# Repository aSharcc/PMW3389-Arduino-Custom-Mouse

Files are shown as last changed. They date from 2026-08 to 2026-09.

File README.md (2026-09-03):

Video Example of Mouse

# PMW3389 Custom DIY Mouse

A fully custom gaming mouse using a PixArt PMW3389.

2 versions. 3.3V/8MHz Arduino Pro Micro (ATmega32U4) and Seeed Studio XIAO ESP32C3.

I also intend for this mouse to be easily repairable.

Be sure to read [BOM.md](docs/BOM.md)

## Key Features

- High performance sensor: 16,000 DPI via PixArt PMW3389
- Modular and Repairable
	- Hotswap Main Switches: Uses Mill-Max 3305 so can be replaced with no soldering
	- Replaceable MCU: Mounted using through-hole pin headers
- Wireless and wired versions.
- Sensor communication through SPI

## Version Comparison

|Features|v2 (Wired)|v3 (Wireless)|
|---|---|---|
|MCU|3.3V/8MHz Arduino Pro Micro (ATmega32U4)|Seeed Studio XIAO ESP32C3|
|Connectivity|Micro-USB|Bluetooth / 2.4GHz Wireless|
|Power Source|Micro-USB|LiPo Battery|
|Production Files|[Files v2](https://github.com/aSharcc/PMW3389-Custom-Mouse/releases/tag/2.0)|[Files v3](https://github.com/aSharcc/PMW3389-Custom-Mouse/releases/tag/3.0)|

## How To Use

**DETAILED INSTRUCTIONS and BOM [HERE](docs/BOM.md)**

1. Order the PCB from a PCB manufacturer (e.g. JLCPCB) with files from specific release.
2. Either:
   - Order PCBA for the SMD components, or
   - Purchase the SMD components and hand solder them.
3. Purchase the components listed in the BOM that are not included in PCBA.
4. Hand solder/install the components not included in PCBA.
5. Download the PMW3389 library.
	- For Wired: [Arduino Library](Firmware/Arduino/README.md) for instructions.
	- For Wireless: **NOT COMPLETED**
6. Download Firmware
	- For Wired: [Arduino Firmware](https://github.com/aSharcc/PMW3389-Custom-Mouse/releases/download/2.0/Mouse.Firmware.ino)
	- For Wireless: **NOT COMPLETED**
7. Flash the firmware to the MCU.
8. Download and print the 3D models.
	- For Wired: [Top](https://github.com/aSharcc/PMW3389-Custom-Mouse/releases/download/2.0/Mouse.Shell.top.gcode.3mf) + [Bottom](https://github.com/aSharcc/PMW3389-Custom-Mouse/releases/download/2.0/Mouse.Shell.bottom.gcode.3mf) + [Scroll](https://github.com/aSharcc/PMW3389-Custom-Mouse/releases/download/2.0/Mouse.Shell.knob.gcode.3mf)
	- For Wireless: **NOT COMPLETED**
9. Add threaded heat inserts to the shell.
10. **For Wireless Only**:
	- **Not Completed** Will include power switch and battery stuff.
11. Assemble the mouse.

## Components

- Sensor: PixArt PMW3389 and LM19-LCT Lens

- MCU: 3.3V/8MHz Arduino Pro Micro (ATmega32U4) or Seeed Studio XIAO ESP32C3

- Switches: 2 x Huano Blue Shell Pink Dot Mouse Switches 

- Scroll Wheel: Rotary Encoder w/Switch (EC11)

- Hot Swap Socket for Switches: 6 x Mill-Max 3305

- SMD Components (0805)
	- 1 x 13 ohm resistor
	- 1 x 10k ohm resistor
	- 5 x 0.1uF capacitor
	- 3 x 10uF capacitor
	- 1 x 4.7uF capacitor
	- 1 x XC6206-1.8V LDO

- PTFE Mouse Skates

- Micro USB Cable for v2 or USB-C cable for v3 charging

- Mounting Hardware
	- 7 x Heat Inserts M2 x 3 x 3.2
	- 3 x M2 x 4 Screw
	- 4 x M2 x 7 Screw

- **FOR V3 ONLY**:
	- 500mAh battery with JST connector
	- SPDT / 1P2T PCB slide switch

## Pinout

|Component|Usage|v2 (3.3v/8MHz Pro Micro)|v3 (XIAO ESP32)|
|---|---|---|---|
|**PMW3389**|NCS|D10|D3|
||MOSI|D16 (MOSI)|D10 (MOSI)|
||MISO|D14 (MISO)|D9 (MISO)|
||SCLK|D15 (SCLK)|D8 (SCLK)|
||MOT|D2 (INT 1)|D4|
|**Rotary Encoder w/Switch**|Rotary Encoder A|D3 (INT 0)|D6|
||Rotary Encoder B|D7 (INT 6)|D0|
||Encoder Switch S2 (Middle Click)|D8|D7|
|**Switches**|Switch 1 (Left Click)|D4|D1|
||Switch 2 (Right Click)|D9|D2|

## Documentation & Credits

- [Build & Design Log](CHANGELOG.md)
- [Third-Party Credits & Libraries](CREDITS.md)
- [MIT License](LICENSE)

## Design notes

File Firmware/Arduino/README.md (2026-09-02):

# PMW3389 Library

PMW3389 driver library for ATmega32u4 based boards. e.g. Sparkfun Pro Micro

## Features

- Register Read and Write
- SROM firmware upload
- Motion Burst Reads (dx, dy, motion flag, SQUAL)
- DPI/CPI set and get. Range of 100-16000, steps of 50

## Hardware Requirements

- 1.8v-2.1v to VDD with decoupling capacitors (10uF and 100nF)
- 1.8v-3.6v to VDDIO  with decoupling capacitors (10uF and 100nF)
- SPI connection with correct voltage (1.8v-3.6v (same as voltage to VDDIO))
- 13ohm Resistor then 1.8v-2.1v to LED1_P with decoupling capacitors (10uF and 100nF)
- VDDPIX to ground through decoupling capacitors (10uF and 100nF)
- GND wired to Ground

## Installation

**PlatformIO** - Copy this folder into your project's 'lib/' folder

**ArduinoIDE** - Copy this folder into your sketchbook's 'libraries/' directory (usually 'Documents/Arduino/libraries/'), then restart the IDE.

**OR**
- Download [Library Zip File](https://github.com/aSharcc/PMW3389-Custom-Mouse/releases/download/2.0/Library.zip)
- Go to ArduinoIDE
- Sketch->include Library->Add .ZIP Library...->Select downloaded .ZIP file

## API Reference

| Method | Description |
|---|---|
| `PMW3389(uint8_t ncsPin)` | Constructor. Sets which pin is used for chip select. |
| `bool begin()` | Initializes SPI, resets the sensor, uploads SROM firmware. Returns `true` if Product_ID verification passes. |
| `uint8_t readRegister(uint8_t regAddr)` | Reads a single register. |
| `void writeRegister(uint8_t regAddr, uint8_t value)` | Writes a single register. |
| `PMW3389_Motion readMotion()` | Performs a burst read. Returns a struct with `isMotion`, `dx`, `dy`, `squal`. |
| `void setDPI(uint16_t dpi)` | Sets sensor resolution. Clamped to 100–16000, rounded down to the nearest 50. |
| `uint16_t getDPI()` | Reads back the currently set DPI. |

## Usage

``` cpp
#include <PMW3389.h>

PMW3389 sensor(10); // NCS on pin 10

void setup() {
    if (!sensor.begin()) {
        // SROM upload or Product_ID check failed
        while (1);
    }
    sensor.setDPI(1600);
}

void loop() {
    PMW3389_Motion motion = sensor.readMotion();
    if (motion.isMotion) {
        // motion.dx, motion.dy available here
    }
}
```

See `examples/BasicMouse` for a complete mouse implementation with buttons and scroll.

## License

Licensed under MIT license.
[LICENSE](/LICENSE)

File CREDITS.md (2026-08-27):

# Third-Party Credits 

This project was developed using the following third-party resources for
reference, comparison, and component integration.

## Firmware & Technical References

* **PixArt PMW3389 Datasheet:** [PixArt Imaging](https://www.pixart.com/products-detail/4/PMW3389DM-T3QU/)

* **PMW3360/PMW3389 Breakout Board:** [kbjunky/PMW3360](https://github.com/kbjunky/PMW3360/) — MIT License.
  Used to compare and verify hardware designs.

* **PMW3389 Arduino Firmware References:**
  * [Creasento/PWM3389_Arduino](https://github.com/Creasento/PWM3389_Arduino/) — GNU GPL v3.0.
  * [mrjohnk/PMW3389DM](https://github.com/mrjohnk/PMW3389DM/) — used as a reference for understanding PMW3389 communication.

  These projects were used for reference and comparison during development.
  The firmware in this project was written independently.

## KiCad Symbols and Footprints

* **PMW3389 Footprint:** [SnapEDA / PixArt PMW3360DM-T2QU](https://www.snapeda.com/parts/PMW3360DM-T2QU/PixArt/view-part/) — SnapEDA licensing terms / applicable Design Exception.

* **Arduino Pro Micro Footprint:** [SnapEDA / SparkFun DEV-12587](https://www.snapeda.com/parts/DEV-12587/SparkFun%20Electronics/view-part/)

* **Mouse Switch Footprint:** [SnapEDA / Omron D2FC-F-7N(100M)](https://www.snapeda.com/parts/D2FC-F-7N(100M)/Omron/view-part/)

* **Other Components:** KiCad built-in libraries — [KiCad](https://www.kicad.org/).

## 3D CAD References

The following third-party 3D models were used during mechanical development
for component placement, clearance checking, and shell design.

These models are not part of the original design work of this project.

* **PMW3360 Sensor:** [GrabCAD](https://grabcad.com/library/pmw3360dm-mouse-sensor-1)
* **Arduino Pro Micro USB-C:** [GrabCAD](https://grabcad.com/library/arduino-pro-micro-usb-type-c-1)
* **Kailh Mouse Switch:** [GrabCAD](https://grabcad.com/library/tiny-switch-kailh-mouse-1)
* **EC11 Rotary Encoder:** [GrabCAD](https://grabcad.com/library/ec11-rotary-encoder-dode-switch-15mm-1)
* **2.54mm Female Pin Header:** [GrabCAD](https://grabcad.com/library/2-54mm-female-pin-header-1)
* **2.54mm Male Pin Header:** [GrabCAD](https://grabcad.com/library/2-54mm-male-pin-header-1)

The PMW3360 model is used as a mechanical reference for the PMW3389 because
the relevant physical package/footprint is shared.

The female and male pin header models are provided under the
**Free Digital Asset Commercial License v1.9**. Where these models are
redistributed, the original license text is retained with the files.

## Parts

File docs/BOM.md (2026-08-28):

# PMW3389 Custom DIY Mouse - Bill of Materials

## Build information

|Item|Specification|
|---|---|
|Project|PMW3389 Custom DIY Mouse|
|Quantity|1 Mouse|
|PCB|Custom Designed|
|Revision|v2|

## 1. PCB

|Item|Quantity|Required?|Notes|
|---|---|---|---|
|Custom PCB|1|Yes|Manufacture by uploading [this](https://github.com/aSharcc/PMW3389-Arduino-Custom-Mouse/releases/download/2.0/DIY_Mouse.zip) to a PCB manufacturer|

This PCB can be assembled by PCB manufacturer or assembled by hand.

## 2. Surface Mount Components (Placed in PCBA)

|PCB Reference|Qty|Component|Part Number/Value|Package|Notes|
|---|---|---|---|---|---|
|U2|1|LDO Regulator|XC6206-1.8V|SOT-23|XC6206-series 1.8 V LDO; equivalent parts must match the schematic's electrical and pinout requirements.|
|R1|1|Resistor|13 Ω|0805|-|
|R2|1|Resistor|10 kΩ|0805|-|
|C1|1|Capacitor|4.7uF|0805|-|
|C2, C3, C6, C8, C10|5|Capacitor|0.1uF/100nF|0805|-|
|C5, C7, C9|3|Capacitor|10uF|0805|-|
**THERE IS NO C4**

## 3. Through Hole Components (Not in PCBA)

These components are intentionally excluded from PCBA and must be installed by hand.

|Item|Quantity|Notes|
|---|---|---|
|Arduino Pro Micro ATmega32U4 3.3V/8MHz|1|**MUST BE 3.3V/8MHz** Microcontroller for mouse|
|PMW3389|1|Mouse sensor|
|EC11|1|**Should be 15mm and "Plum Handle".**Rotary encoder (Scroll Wheel)|
|Mill-Max 3305 socket|6|Allows for Hot-Swappable switches|
|Huano Blue Shell Pink Dot|2|Mouse switches (Buttons)|
|12-Pin Male Pin Header, 2.54mm Pitch, 1×12|2|Should come with Pro Micro|
|12-Pin Female Pin Header, 2.54mm Pitch, 1×12|2|Allows for replaceable Microcontroller|

## 4. Other Stuff

|Item|Quantity|Notes|
|---|---|---|
|LM-19-LCT Lens|1|Lens for PMW3389, usually sold together|
|PTFE Mouse Skates|5-10|Placed on bottom of mouse to allow for smooth movement|
|USB Cable|1|Get 1m+|

## 5. 3D Printed Parts
|Item|Source|Notes|
|---|---|---|
|Top Shell|[Top Shell 3mf](Mechanical/v2/STLs/Mouse Shell top.3mf)|Keep at rotation, it helps with stepping|
|Bottom shell|[Bottom Shell 3mf](Mechanical/v2/STLs/Mouse Shell bottom.3mf)|-|
|Scroll Knob|[Scroll Knob 3mf](Mechanical/v2/STLs/Mouse Shell knob.3mf)|-|

## 6. Mounting Hardware

|Item|Quantity|Notes|
|---|---|---|
|M2 x 3 x 3.2 Heat Inserts|7|-|
|M2 x 6 Screws|4|-|
|M2 x 4 Screws|3|-|

## 7. Overall Manufacturing

### PCB

- Quantity: 1
- Download [GBR Files](https://github.com/aSharcc/PMW3389-Arduino-Custom-Mouse/releases/download/2.0/DIY_Mouse.zip)
- Download PCBA Files [BOM](https://github.com/aSharcc/PMW3389-Arduino-Custom-Mouse/releases/download/2.0/bom.csv) and [CPL](https://github.com/aSharcc/PMW3389-Arduino-Custom-Mouse/releases/download/2.0/positions.csv)
- Order from PCB manufacturer e.g. [JLCPCB](https://cart.jlcpcb.com/quote)
- PCBA is optional for small surface mount components but can be hand-soldered
- All components not included in PCBA must be installed by hand as required by the design.

### Purchasing Parts

Do not purchase the components listed in **Section 2: Surface Mount Components**.

These components will be supplied and assembled by the PCB manufacturer.

The components in **Section 3: Through Hole Components** must still be purchased separately and installed by hand.

### Shell

- 3D print the following files:
    - [Top Shell](Mechanical/v2/STLs/Mouse Shell top.3mf)
    - [Bottom Shell](Mechanical/v2/STLs/Mouse Shell bottom.3mf)
    - [Scroll Knob](Mechanical/v2/STLs/Mouse Shell knob.3mf)
- Insert heat inserts into the holes on the top and bottom shell

### Firmware

You can use either Arduino IDE or VS Code with PlatformIO extension

#### Arduino IDE

##### Library

You can install the PMW3389 library using either method:

**Option 1 — Included library**

1. Download [Firmware.zip](https://github.com/aSharcc/PMW3389-Arduino-Custom-Mouse/releases/download/2.0/Firmware.zip).
2. Open Arduino IDE.
3. Go to **Sketch → Include Library → Add .ZIP Library...**
4. Select `Firmware.zip`.

**Option 2 — Arduino Library Manager**

1. Open Arduino IDE.
2. Open **Library Manager**.
3. Search for `PMW3389`.
4. Install the library by **sharc !!**.

##### Selecting Correct Board

**If you upload the code with the wrong board you can brick your arduino!!**

1. Open Arduino IDE
2. Click **File->Preferences or Arduino->Preferences**
3. Find **Additional Boards Manager URLs** field
4. Paste this link:
``` markdown
https://raw.githubusercontent.com/sparkfun/Arduino_Boards/main/IDE_Board_Manager/package_sparkfun_index.json
```
5. Click **OK**
6. Click **Tools->Board->Board Manager**
7. Search for `SparkFun AVR Boards`
8. Click **Tools->Board->Sparkfun AVR Boards**
9. Select your board
10. Click **Tools->Processor**
11. Select **3.3V/8MHz**

##### Mouse Code

1. Download [Basic Mouse](Firmware/examples/BasicMouse/BasicMouse.ino)
2. Plug in Arduino Pro Micro
3. Open with Arduino IDE
4. Select COM port with Arduino Pro Micro
5. Click **Upload** in top left

#### VSCode w/ PlatformIO

1. Download [Firmware Directory](Firmware)
2. Open **Firmware/examples/BasicMouse/BasicMouse.ino**
3. Click **Upload** in bottom left

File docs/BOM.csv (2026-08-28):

Item Name | Qty | Price (total) (GPB) | Item link | Notes
Custom PCB | 1 | £32.88 w/ shipping | https://cart.jlcpcb.com/quote | PCB v2
Arduino Pro Micro ATmega32U4 3.3V/8MHz | 1 | £5.90 | https://www.aliexpress.com/item/1005007240573013.html | Must be 3.3v/8MHz
PMW3389 Sensor + LM19-LCT Lens | 1 | £7.55 | https://www.aliexpress.com/item/1005007468783392.html | -
EC11 Rotary Encoder | 1 | £0.85 | https://www.aliexpress.com/item/1005007644083514.html | -
Mill-Max 3305 Socket | 6 | £3.00 | https://keebd.com/en-gb/products/mill-max-socket-3305-pack-of-10 | -
Huano Blue Shell Pink Dot | 2 | £2.77 | https://www.aliexpress.com/item/1005004754415184.html | -
Single Row Pin Female Header Socket Pitch 2.54mm 1x12 pin | 2 | £1.20 | https://www.aliexpress.com/item/4001198421663.html | -
13 Ω Resistor | 1 | £1.25 | https://www.aliexpress.com/item/1005001794062302.html | -
10 kΩ Resistor | 1 | £1.25 | https://www.aliexpress.com/item/1005001794062302.html | -
100 nF Capacitor | 5 | £3 | https://www.aliexpress.com/item/1005010243722146.html | -
10 µF Capacitor | 3 | £6.02 | https://www.aliexpress.com/item/1005010243722146.html | -
4.7 µF Capacitor | 1 | £5.77 | https://www.aliexpress.com/item/1005010243722146.html | -
XC6206-1.8V 65K5 LDO | 1 | £0.95 | https://www.aliexpress.com/item/1005005560879957.html | -
PTFE Mouse Skates | 10 | £1.05 | https://www.aliexpress.com/item/1005007319381356.html | -
USB Cable | 1 | £0.90 | https://www.aliexpress.com/item/1005003391567749.html | -
M2 Hardware Kit | 1 | £6.66 | https://www.aliexpress.com/item/1005004837433548.html | -
3D Printing Filament | 1 | £21.99 | https://uk.store.bambulab.com/products/pla-tough-upgrade?id=624454208526409776 | -

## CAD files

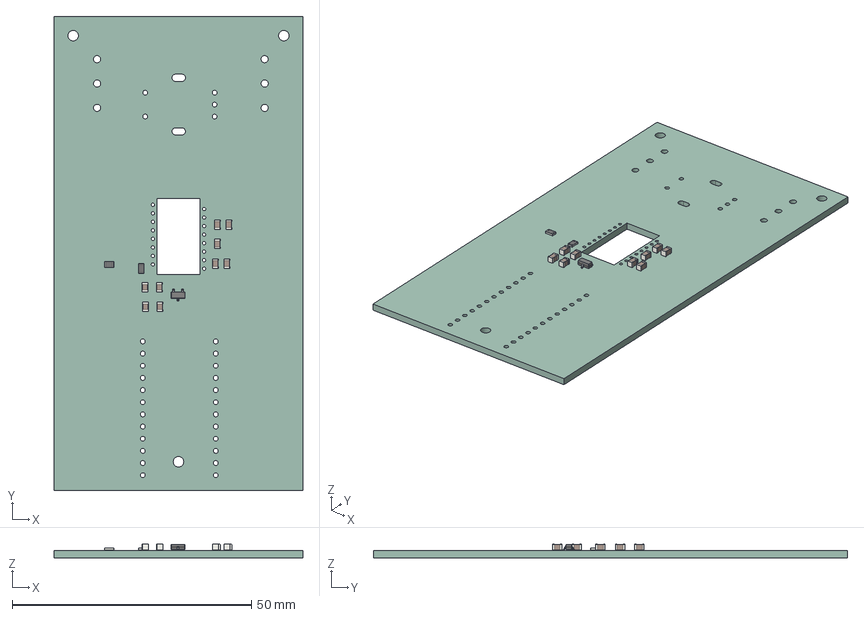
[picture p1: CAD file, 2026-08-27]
Hardware/v2 (wired)/DIY_Mouse.step
52.0 x 99.0 x 2.84 mm
R_0805_2012Metric x 2
C_0805_2012Metric x 9
SOT-23
DIY_Mouse_PCB

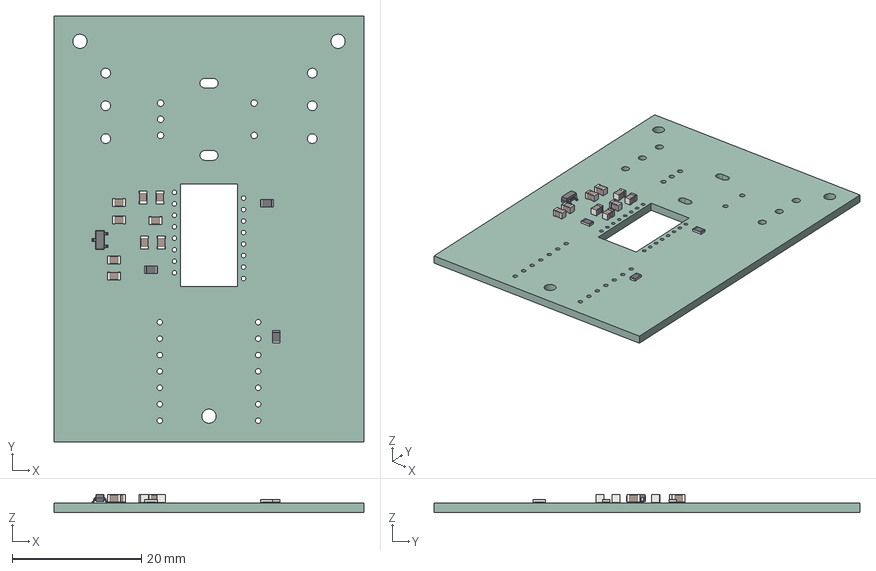
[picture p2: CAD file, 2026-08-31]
Hardware/v3 (wireless)/Mouse v3.step
48.0 x 66.0 x 2.84 mm
C_0805_2012Metric x 9
SOT-23-3
R_0805_2012Metric x 3
MouB548_PCB

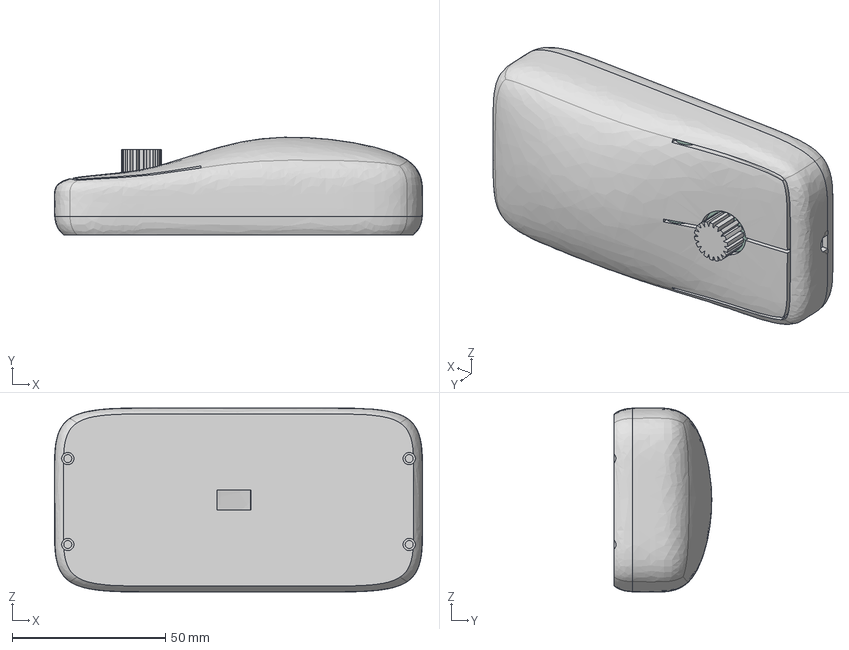
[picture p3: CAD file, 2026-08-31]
Mechanical/v2 (wired)/Mouse Shell v2.step
120.0 x 31.8 x 60.0 mm

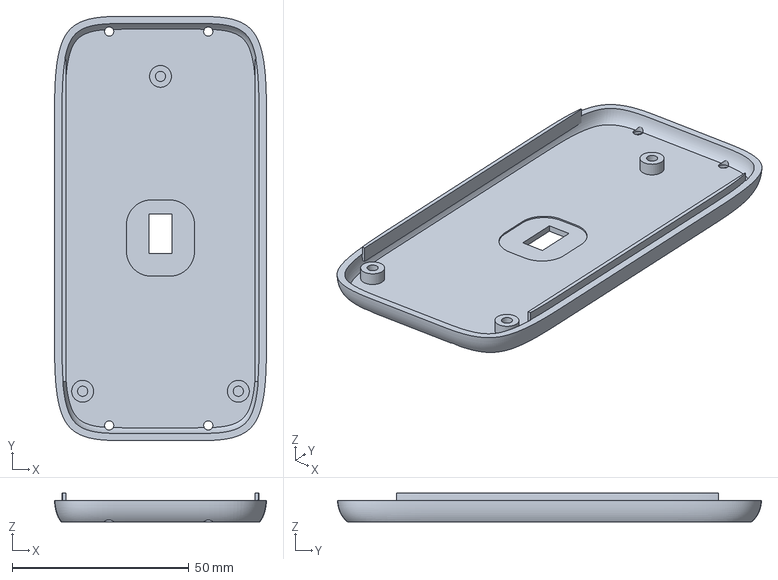
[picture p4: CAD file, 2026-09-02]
Mechanical/v2 (wired)/STLs/Mouse Shell bottom.3mf
59.9 x 119.9 x 8.16 mm

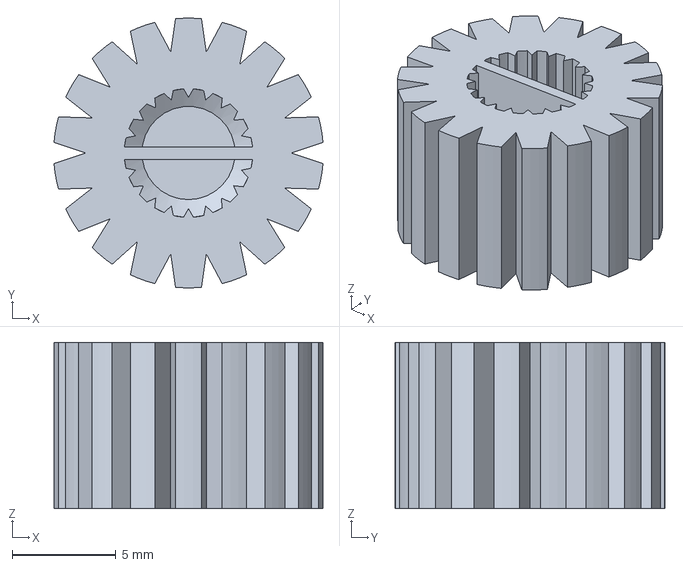
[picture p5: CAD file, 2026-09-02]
Mechanical/v2 (wired)/STLs/Mouse Shell knob.3mf
13.0 x 13.0 x 8.00 mm

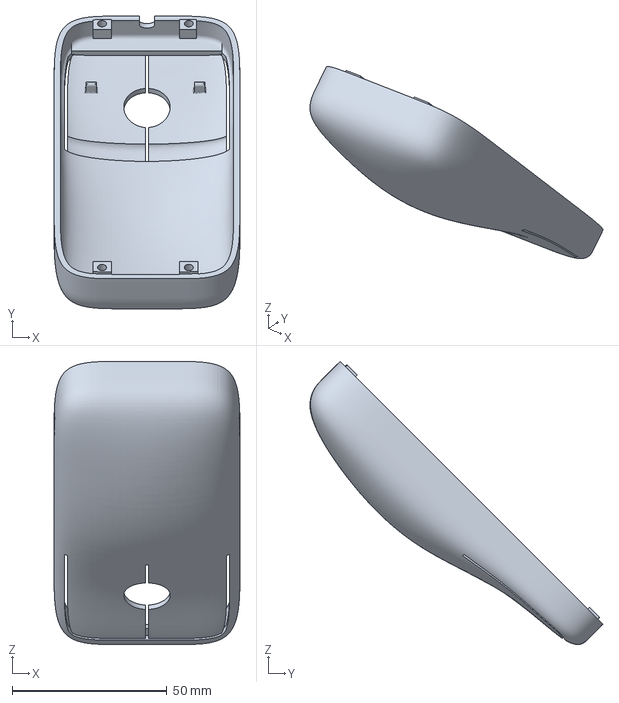
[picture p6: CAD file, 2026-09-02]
Mechanical/v2 (wired)/STLs/Mouse Shell top.3mf
60.0 x 94.6 x 91.4 mm

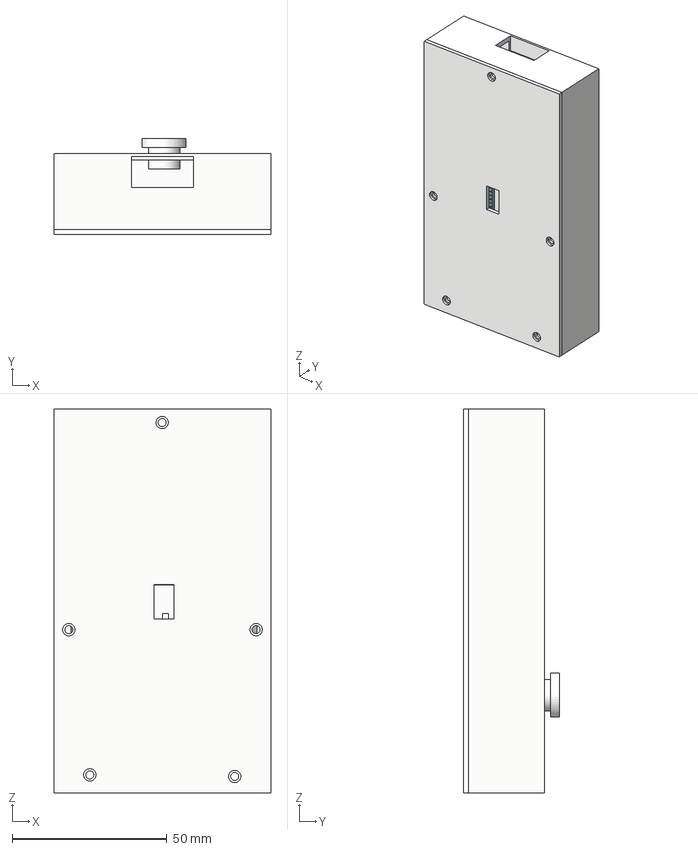
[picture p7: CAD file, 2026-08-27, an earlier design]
Mechanical/v1 (wired)/Mouse Shell.step
70.0 x 31.2 x 124.0 mm

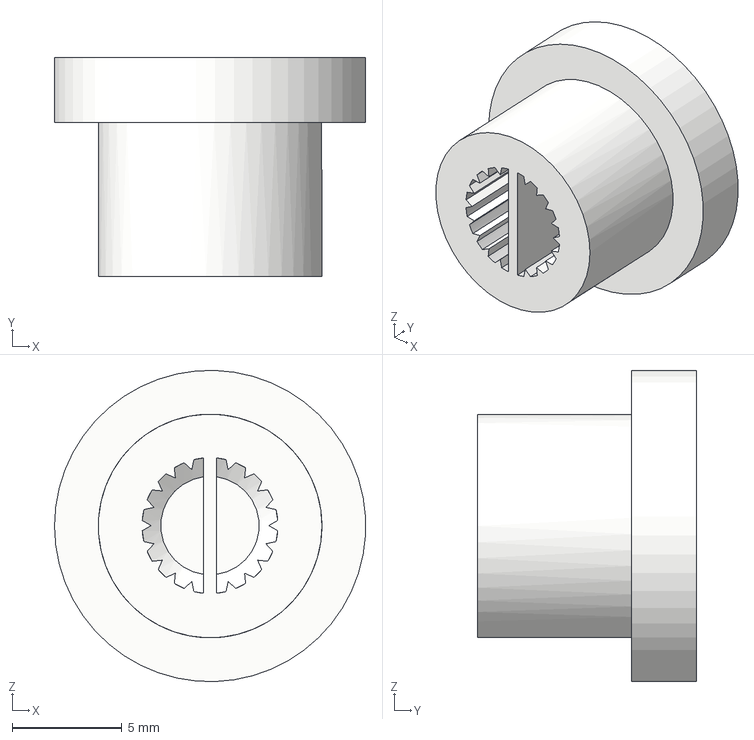
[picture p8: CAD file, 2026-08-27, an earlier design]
Mechanical/v1 (wired)/STLs/Mouse Shell knob.3mf
14.2 x 10.00 x 14.2 mm

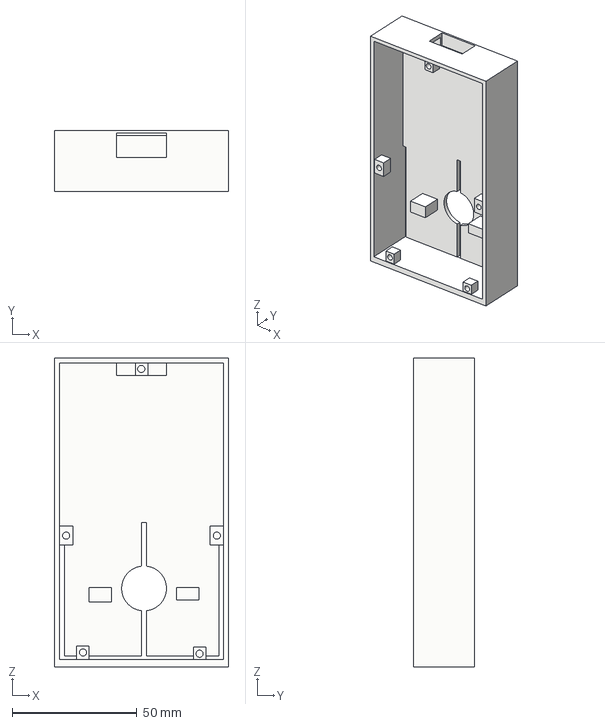
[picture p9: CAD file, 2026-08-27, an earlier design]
Mechanical/v1 (wired)/STLs/Mouse Shell top.3mf
70.0 x 24.5 x 124.0 mm

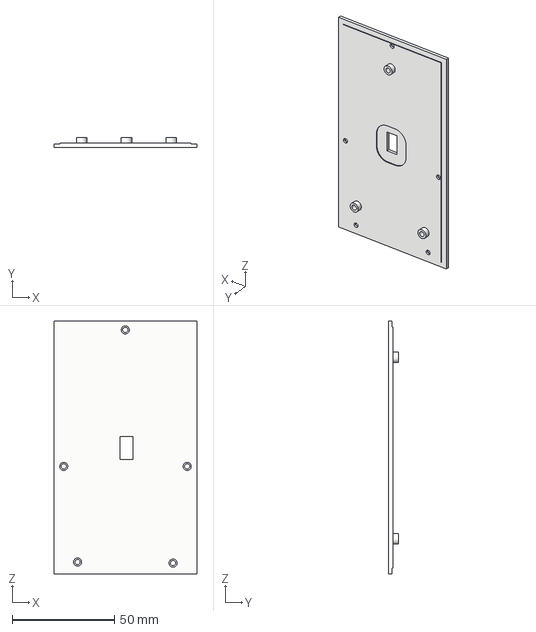
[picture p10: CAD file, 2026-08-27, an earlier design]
Mechanical/v1 (wired)/STLs/Mouse Shell bottom.3mf
70.0 x 4.76 x 124.0 mm

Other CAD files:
Mechanical/v2 (wired)/STLs/Mouse Shell knob.gcode.3mf
Mechanical/v2 (wired)/STLs/Mouse Shell bottom.gcode.3mf
Mechanical/v2 (wired)/STLs/Mouse Shell top.gcode.3mf
Mechanical/v1 (wired)/Mouse Shell.f3z
Mechanical/v2 (wired)/Mouse Shell v2.f3z

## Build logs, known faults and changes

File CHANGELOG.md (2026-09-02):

# Build and Design Log

## 22/07/2026

- Created project folder structure
- Set up git repository
- Fixed formatting on .md files
- Added symbol and footprints for components to KiCad
- Created PCB schematic
- Bought components

### Next steps

- Create PCB 
- Check PCB
- Order PCB
- Solder Components to PCB
- Test PCB
- Design Mouse Shell 3D file

## 23/07/2026

- Designed PCB
- Edited schecatics
- Checked PCB
- Created .GBR and .DRL files for PCB manufacturing
- Added license details
- Updated Credits and Readme
- Ordered PCB

### Next steps

- Solder components
- Create firmware
- Test PCB
- Design 3D model for mouse shell

## 24/07/2026 to 24/08/2026

- Soldered PCB
- Tested PCB
- Created Firmware
- Tested Firmware
- Updated Readme and Credits

### Next steps

- Create 3D model for shell
- Create v2 of circtui board addressing issues (mouse switches are backwards, scroll wheel is awkward, lens cutout is too small)

## 25/08/2026

- Added 3d models to pcb to design shell
- Updated pcb design (expanded cutout for lens, flipped switched)
- Updated Credits
- Added silkscreen logo to PCB
- 3d modeled shell

### Next steps

- Change scroll wheel/rotary encoder on pcb
- Print shell
- add threaded heat inserts into shell
- assemble shell
- test shell
- Order new scroll wheel and more PMW3389 sensors
- Adjust shell to accomodate new scroll wheel
- Expand screw through-holes
- countersink screws on bottom
- expand mouse buttons

## 26/08/2026

- 3d printed mouse shell
- Assembled mouse shell (heat inserts, screws)
- Tested shell
- Created new shell design (Countersunk screws, larger through-holes for screws, heat inserts line up correctly, larger mouse buttons)
- Printed, assembled and tested new shell design

### Next Steps

- Test mouse overall
- Create cutout for usb wire
- Order new PCBs
- Make shell more ergonomic
- add size buttons
- add dpi control

## 27/08/2026

- Added more screws to shell
- Added hole for usb cable at front of shell
- Created scroll wheel cutout
- Tested mouse - fully functional
- Completed PCB v2
    - Minimised pcb size
    - Flipped arduino
- Creating shell v2
    - Accomodate for new PCB
    - Make more ergonomic
    - Added ridges to scroll whell for better grip
- Printed shell v2

## Next Steps

- Complete PCB v2
    - Order PCBs
    - Order PMW3389 sensors

## 28/08/2026

- Iterating on shell v2
    - Made USB cable cutout smaller to clamp cable
    - Extended border around heat insert holes to stop them from collapsing
- Updated README with instructions for creating the mouse
- Created BOM.md
- Created BOM.csv
- Updated .gitignore
- Cleaned up repo files
- Exported manufacture files for PCB
- Created release on GitHub with PCB manufacture files and firmware

### Next Steps

- Complete PCB v2 **(Wating for funding from stardance)**
    - Order PCBs
    - Order PMW3389 sensors

## 29/08/2026

- Created PCB v3 (Wireless)
- Cleaned up GitHub repo
- Exported PCB files
- Created new release on GitHub

### Next Steps

- Order PCBs
- Order PMW3389 sensors
- Create shell for v3

## 30/08/2026

- Updated shell v2 (Changed click mechanism)
- Printed new shell v2

### Next Steps

- Create shell for v3 (wireless)
- Order PCB for v2 (wired) and v3 (wireless)

## 31/08/2026

- Updated PCB v2 and v3 to follow DFM guidelines and increased size of lens cutout

### Next Steps

- Create shell v3
- Order PCB for v2 (wired) and v3 (wireless)

## 02/09/2026

- Updated Readme 
- Created 3d printing files
- Printed out new top shell

### Next Steps

- Center sensor on PCB v3
- Create shell v3
- Order PCB for v2 (wired) and v3 (wireless)

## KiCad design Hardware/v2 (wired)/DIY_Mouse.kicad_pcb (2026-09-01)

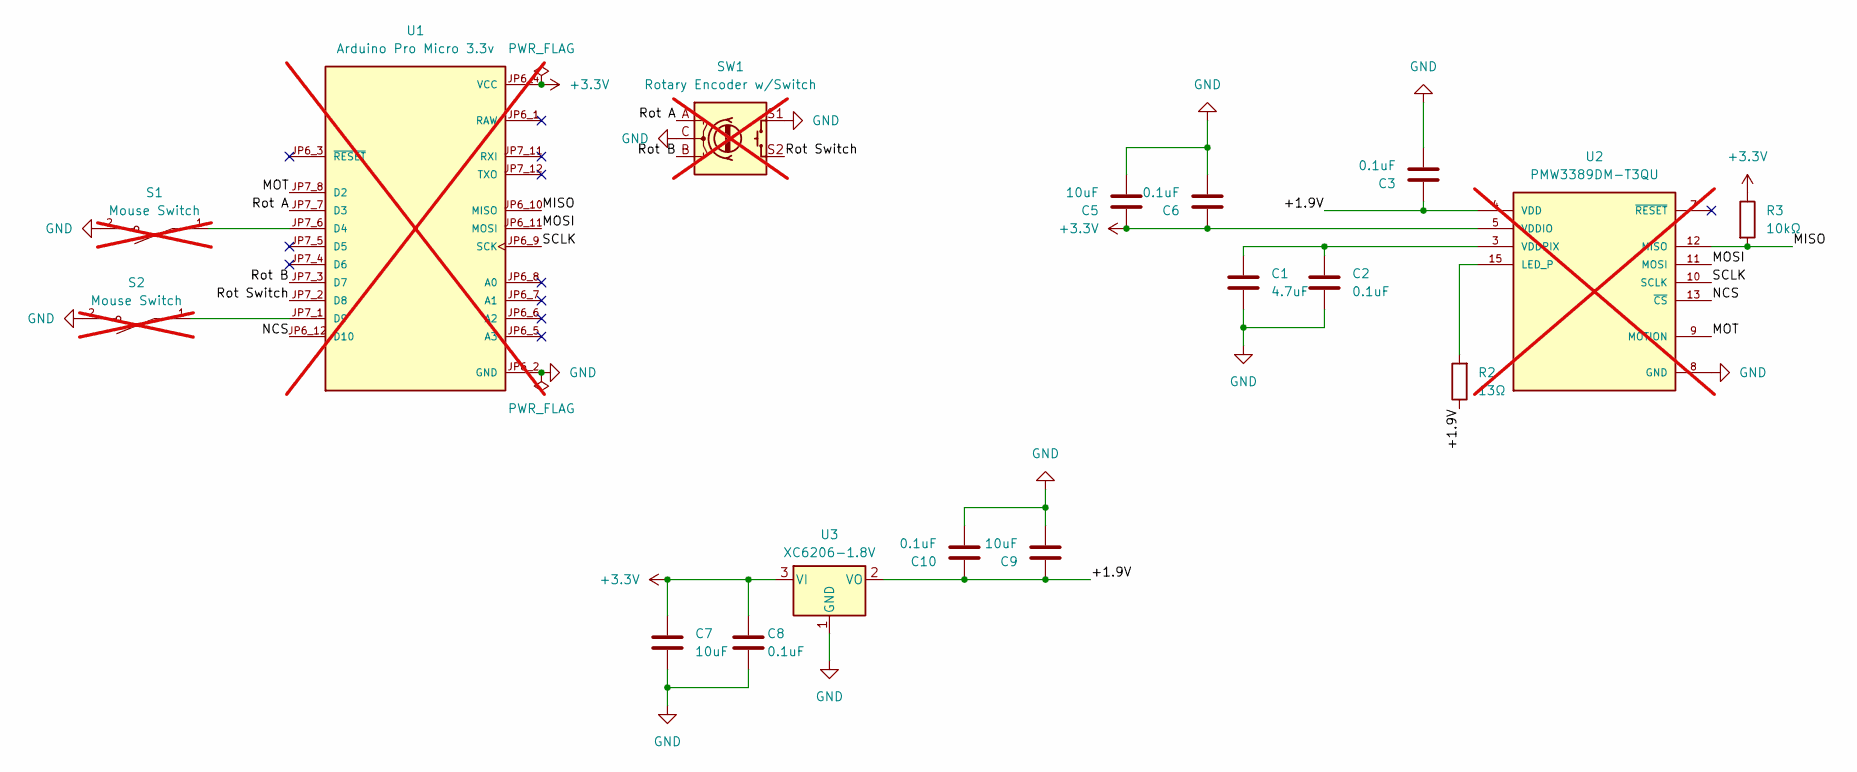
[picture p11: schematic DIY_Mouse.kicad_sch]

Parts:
C1: 4.7uF; C_0805_2012Metric_Pad1.18x1.45mm_HandSolder; LCSC Part # C354262
C2, C3, C6, C8, C10: 0.1uF; C_0805_2012Metric_Pad1.18x1.45mm_HandSolder; LCSC Part # C519981
C5, C7, C9: 10uF; C_0805_2012Metric_Pad1.18x1.45mm_HandSolder; LCSC Part # C326595
R2: 13Ω; R_0805_2012Metric_Pad1.20x1.40mm_HandSolder; LCSC Part # C2933313
R3: 10kΩ; R_0805_2012Metric_Pad1.20x1.40mm_HandSolder; LCSC Part # C881248
S1, S2: Mouse Switch; SW_D2FC-F-7N_100M_; PARTREV 2023-2024; not fitted
SW1: Rotary Encoder w/Switch; RotaryEncoder_Alps_EC11E-Switch_Vertical_H20mm; not fitted
U1: Arduino Pro Micro 3.3v; MODULE_DEV-12587; PARTREV 2/12/2015; not fitted
U2: PMW3389DM-T3QU; PMW3360; MANUFACTURER_PART_NUMBER PMW3360DM-T2QU; not fitted
U3: XC6206-1.8V; SOT-23; LCSC Part # C49195704

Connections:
+3.3V: C5.1, C6.2, C7.2, C8.1, R3.1, U1.JP6_4 (VCC), U2.5 (VDDIO), U3.3 (VI)
/+1.9V: C3.2, C9.2, C10.1, R2.1, U2.4 (VDD), U3.2 (VO)
/MISO: R3.2, U1.JP6_10 (MISO), U2.12 (MISO)
/MOSI: U1.JP6_11 (MOSI), U2.11 (MOSI)
/MOT: U1.JP7_8 (D2), U2.9 (MOTION)
/NCS: U1.JP6_12 (D10), U2.13 (~CS)
/Rot A: SW1.A, U1.JP7_7 (D3)
/Rot B: SW1.B, U1.JP7_3 (D7)
/Rot Switch: SW1.S2, U1.JP7_2 (D8)
/SCLK: U1.JP6_9 (SCK), U2.10 (SCLK)
GND: C1.1, C2.2, C3.1, C5.2, C6.1, C7.1, C8.2, C9.1, C10.2, S1.2, S2.2, SW1.C, SW1.S1, U1.JP6_2 (GND), U1.JP7_9 (GND), U1.JP7_10 (GND), U2.8 (GND), U3.1 (GND)
unnamed: S1.1, U1.JP7_6 (D4)
unnamed: S2.1, U1.JP7_1 (D9)
unnamed: R2.2, U2.15 (LED_P)
unnamed: C1.2, C2.1, U2.3 (VDDPIX)

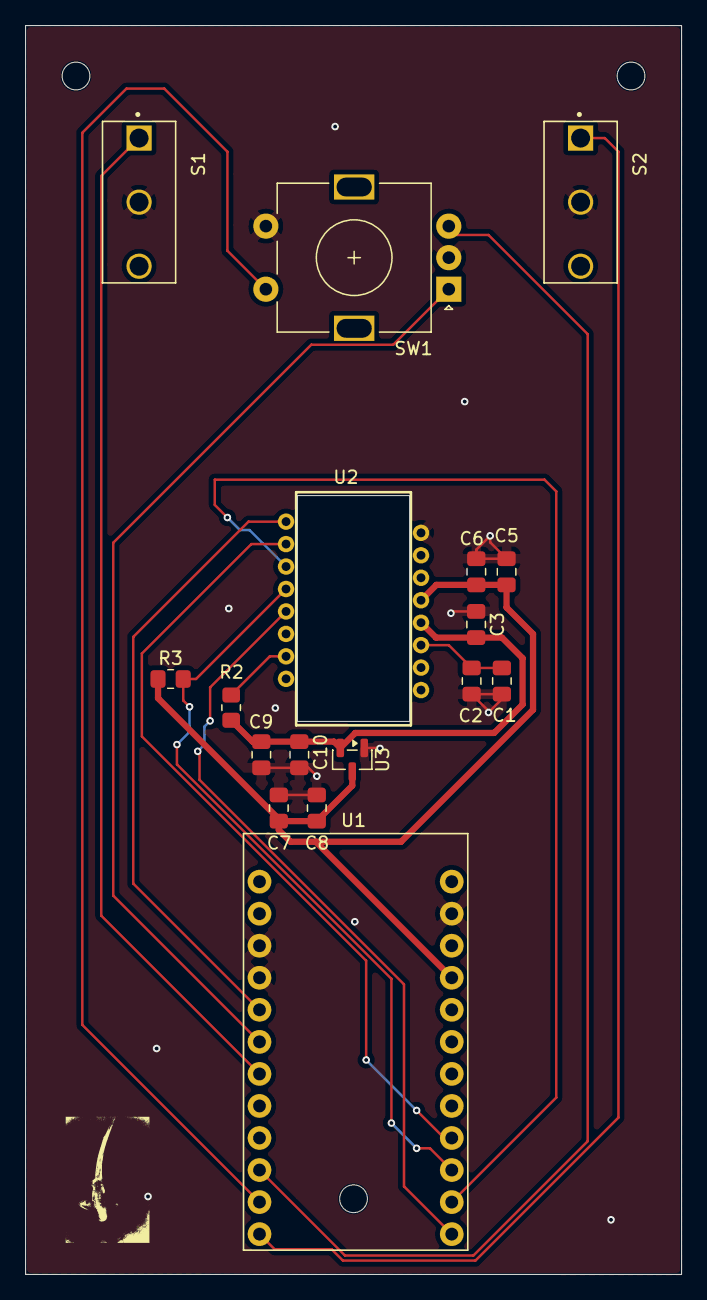
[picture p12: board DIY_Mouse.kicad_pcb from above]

Board: 2 copper layers, 52.0 x 99.0 mm, 17 parts (0 on the bottom side), 15 nets.

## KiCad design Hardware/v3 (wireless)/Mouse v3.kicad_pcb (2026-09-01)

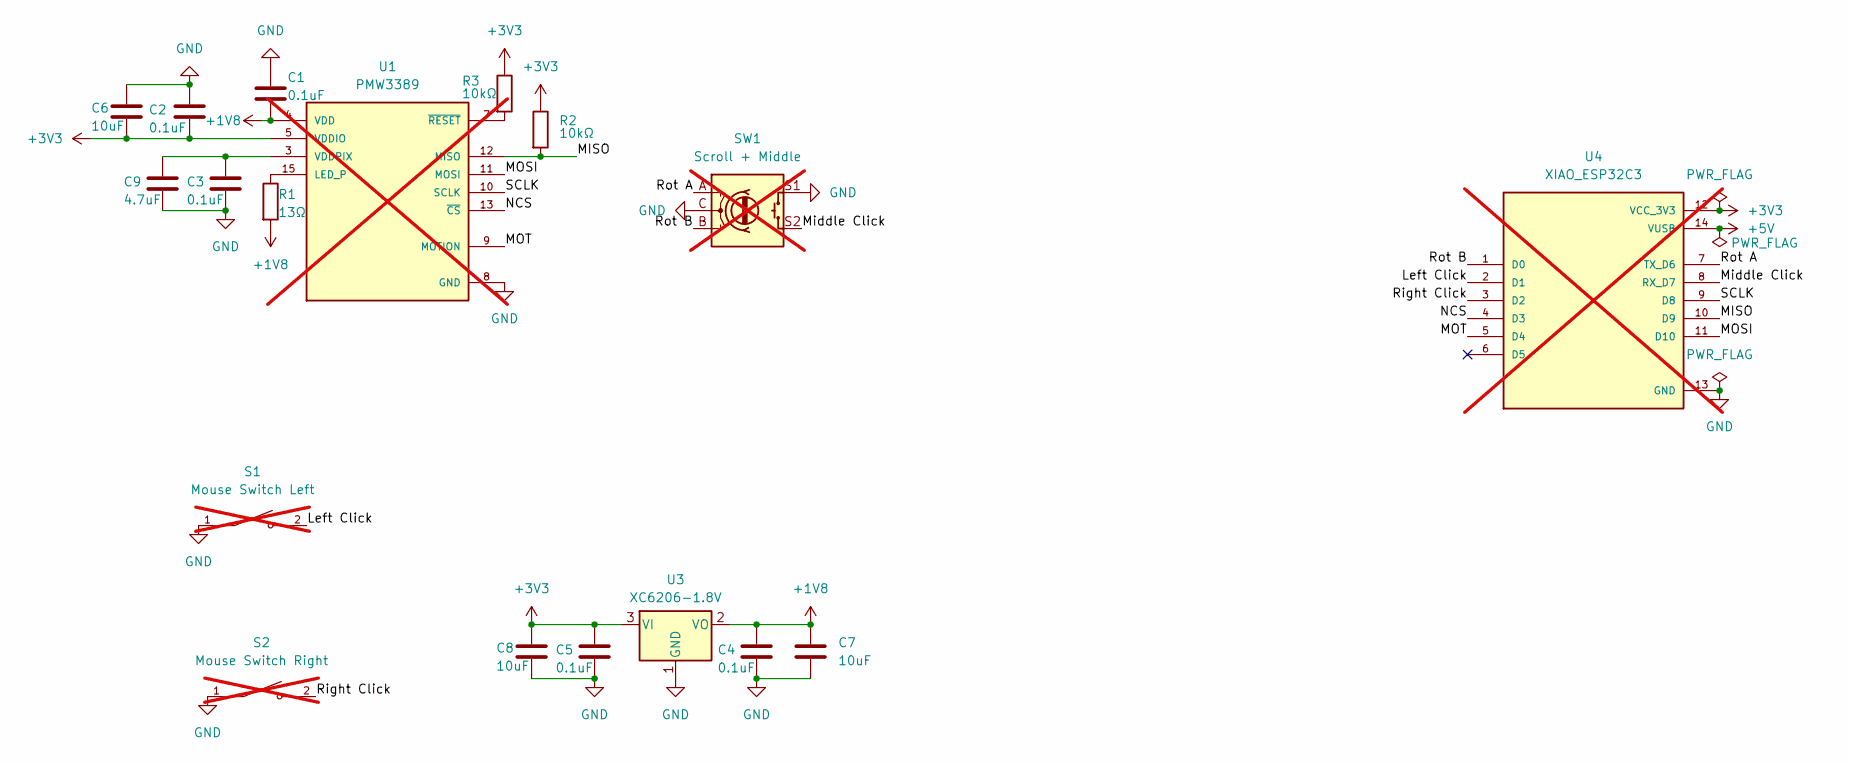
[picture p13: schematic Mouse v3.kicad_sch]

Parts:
C1, C2, C3, C4, C5: 0.1uF; C_0805_2012Metric_Pad1.18x1.45mm_HandSolder
C6, C7, C8: 10uF; C_0805_2012Metric_Pad1.18x1.45mm_HandSolder
C9: 4.7uF; C_0805_2012Metric_Pad1.18x1.45mm_HandSolder
R1: 13Ω; R_0805_2012Metric_Pad1.20x1.40mm_HandSolder
R2, R3: 10kΩ; R_0805_2012Metric_Pad1.20x1.40mm_HandSolder
S1: Mouse Switch Left; SW_D2FC-F-7N_100M_; PARTREV 2023-2024; not fitted
S2: Mouse Switch Right; SW_D2FC-F-7N_100M_; PARTREV 2023-2024; not fitted
SW1: Scroll + Middle; RotaryEncoder_Alps_EC11E-Switch_Vertical_H20mm; not fitted
U1: PMW3389; PMW3360; MANUFACTURER_PART_NUMBER PMW3360DM-T2QU; not fitted
U3: XC6206-1.8V; SOT-23-3
U4: XIAO_ESP32C3; MODULE_XIAO_ESP32C3; PARTREV 23/05/2022; not fitted

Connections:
+1V8: C1.2, C4.1, C7.1, R1.2, U1.4 (VDD), U3.2 (VO)
+3V3: C2.2, C5.1, C6.2, C8.1, R2.1, R3.1, U1.5 (VDDIO), U3.3 (VI), U4.12 (VCC_3V3)
+5V: U4.14 (VUSB)
/Left Click: S1.2, U4.2 (D1)
/MISO: R2.2, U1.12 (MISO), U4.10 (D9)
/MOSI: U1.11 (MOSI), U4.11 (D10)
/MOT: U1.9 (MOTION), U4.5 (D4)
/Middle Click: SW1.S2, U4.8 (RX_D7)
/NCS: U1.13 (~CS), U4.4 (D3)
/Right Click: S2.2, U4.3 (D2)
/Rot A: SW1.A, U4.7 (TX_D6)
/Rot B: SW1.B, U4.1 (D0)
/SCLK: U1.10 (SCLK), U4.9 (D8)
GND: C1.1, C2.1, C3.2, C4.2, C5.2, C6.1, C7.2, C8.2, C9.2, S1.1, S2.1, SW1.C, SW1.S1, U1.8 (GND), U3.1 (GND), U4.13 (GND)
unnamed: R1.1, U1.15 (LED_P)
unnamed: C3.1, C9.1, U1.3 (VDDPIX)
unnamed: R3.2, U1.7 (~RESET)

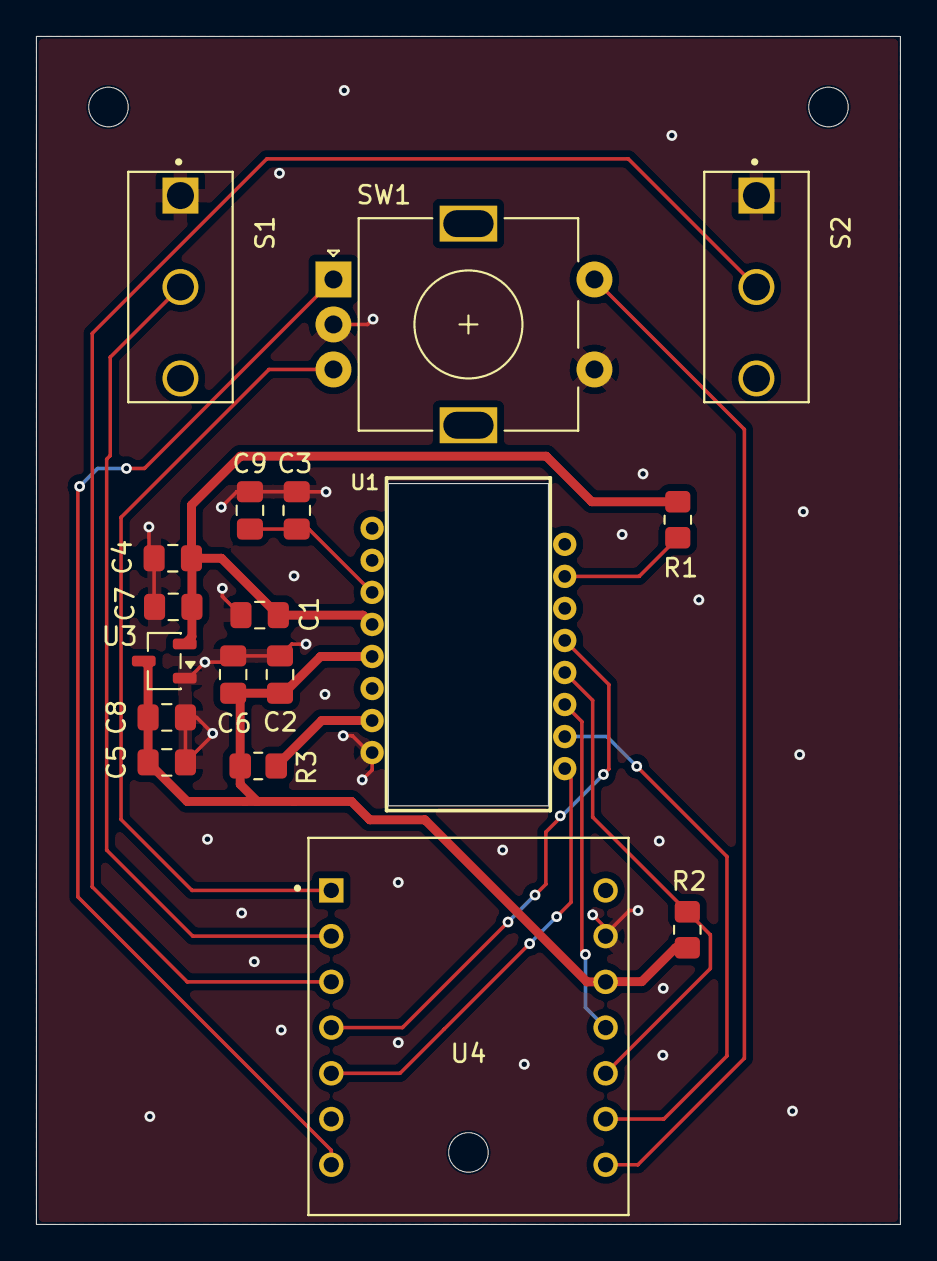
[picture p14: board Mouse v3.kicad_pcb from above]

Board: 2 copper layers, 48.0 x 66.0 mm, 18 parts (0 on the bottom side), 16 nets.

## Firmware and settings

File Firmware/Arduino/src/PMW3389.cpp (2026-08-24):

    #include "PMW3389.h" // Include the header file for the PMW3389 class 
    #include "utility/PMW3389_Srom.h" // Include the header file for the PMW3389 SROM data

    PMW3389::PMW3389(uint8_t ncsPin) {
        _ncsPin = ncsPin; // Defines the private chip select pin for the PMW3389 sensor
    }

    bool PMW3389::begin() {
        pinMode(_ncsPin, OUTPUT); // Set the chip select pin as an output on arduino
        digitalWrite(_ncsPin, HIGH); // Set the chip select pin high to stop communication with the PMW3389 sensor
        SPI.begin(); // Initialize the SPI library
        writeRegister(0x3B, 0xB6); // Write 0xB6 to the power up reset register to reset the PMW3389 sensor
        delay(50); // Wait for 50 milliseconds for chip to reboot
        // Ensure SPI is in a known state by toggling the chip select pin
        digitalWrite(_ncsPin, HIGH); // Set the chip select pin high to stop communication with the PMW3389 sensor
        delayMicroseconds(40); // Wait for 40 microseconds
        digitalWrite(_ncsPin, LOW); // Set the chip select pin low to start communication with the PMW3389 sensor
        delayMicroseconds(40); // Wait for 40 microseconds
        digitalWrite(_ncsPin, HIGH); // Set the chip select pin high to stop communication with the PMW3389 sensor
        return uploadSROM(); // Call the uploadSROM function to upload the SROM data to the PMW3389 sensor
    }

    bool PMW3389::uploadSROM() {
        writeRegister(0x10, 0x20); // Disables rest mode
        writeRegister(0x3A, 0x5A); // Resets the PMW3389 sensor
        delay(50); // Wait for 50 milliseconds for chip to reboot
        readRegister(0x02); // Read the motion register to clear it
        readRegister(0x03); // read the delta x low register to clear it
        readRegister(0x04); // read the delta x high register to clear it
        readRegister(0x05); // read the delta y low register to clear it
        readRegister(0x06); // read the delta y high register to clear it
        writeRegister(0x13, 0x1D); // Arms the SROM download
        delay(10); // Wait for 10 milliseconds for the PMW3389 sensor to arm the SROM download
        writeRegister(0x13, 0x18); // Starts the SROM download state
        SPI.beginTransaction(SPISettings(2000000, MSBFIRST, SPI_MODE3)); // Start an SPI transaction with a clock speed of 2 MHz, MSB first, and SPI mode 3
        digitalWrite(_ncsPin, LOW); // Set the chip select pin low to start communication with the PMW3389 sensor
        SPI.transfer(0x62 | 0x80); // Set MSB to 1 to indicate a write operation and send the Register address to write to (0x62)
        delayMicroseconds(15); // Wait for 15 microseconds to allow the PMW3389 sensor to process the request
        for (uint16_t i = 0; i < 4094; i++) {
            SPI.transfer(pgm_read_byte(&PMW3389_SROM[i])); // Send the SROM data to the PMW3389 sensor, reading each byte from program memory
            delayMicroseconds(15); // Wait for 15 microseconds to allow the PMW3389 sensor to process the request
        }
        delayMicroseconds(2); 
        digitalWrite(_ncsPin, HIGH); // Set the chip select pin high to stop communication with the PMW3389 sensor
        SPI.endTransaction(); // End the SPI transaction
        delayMicroseconds(200); // Wait for 200 microseconds to allow the PMW3389 sensor to process the request
        readRegister(0x2A); // Read the SROM_ID register to verify that the SROM upload was successful
        if (readRegister(0x00) != 0x47) // Read the product ID register to verify that the PMW3389 sensor is responding correctly
            return false; // Return false if the product ID is not correct
        writeRegister(0x10, 0x00); // Write 0x00 to the config2 register to set the PMW3389 sensor to normal operation mode
        return true; // Return true if the SROM upload was successful and the product ID is correct
    }

    uint8_t PMW3389::readRegister(uint8_t regAddr) {
        SPI.beginTransaction(SPISettings(2000000, MSBFIRST, SPI_MODE3)); // Start an SPI transaction with a clock speed of 2 MHz, MSB first, and SPI mode 3
        digitalWrite(_ncsPin, LOW); // Set the chip select pin low to start communication with the PMW3389 sensor
        SPI.transfer(regAddr & 0x7F); // Send the register address to read from, with the MSB set to 0 to indicate a read operation
        delayMicroseconds(160); // Wait to allow the PMW3389 sensor to process the request
        uint8_t data = SPI.transfer(0x00); // Recieve the data from the PMW3389 sensor by sending a dummy byte (0x00)
        digitalWrite(_ncsPin, HIGH); // Set the chip select pin high to stop communication with the PMW3389 sensor
        SPI.endTransaction(); // End the SPI transaction
        delayMicroseconds(20); // 
        return data; // Return the data read from the PMW3389 sensor
    }

    void PMW3389::writeRegister(uint8_t regAddr, uint8_t value) {
        SPI.beginTransaction(SPISettings(2000000, MSBFIRST, SPI_MODE3)); // Start an SPI transaction with a clock speed of 2 MHz, MSB first, and SPI mode 3
        digitalWrite(_ncsPin, LOW); // Set the chip select pin low to start communication with the PMW3389 sensor
        SPI.transfer(regAddr | 0x80); // Send the register address to write to, with the MSB set to 1 to indicate a write operation
        SPI.transfer(value); // Send the value to write to the PMW3389 sensor
        digitalWrite(_ncsPin, HIGH); // Set the chip select pin high to stop communication with the PMW3389 sensor
        SPI.endTransaction(); // End the SPI transaction
        delayMicroseconds(180); // 
    }
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

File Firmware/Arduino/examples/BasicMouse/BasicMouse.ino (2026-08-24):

#include <PMW3389.h> // Include the header file for the PMW3389 class
#include <Mouse.h> // Include the header file for the Arduino Mouse library

#define NCS_PIN 10 // Define the chip select pin for the PMW3389 sensor
#define LC_PIN 4 // Define the pin for the mouse button
#define RC_PIN 9 // Define the pin for the mouse button
#define MC_PIN 8 // Define the pin for the mouse button
#define Rot_A_PIN 3 // Define the pin for the rotary encoder
#define Rot_B_PIN 7 // Define the pin for the rotary encoder
#define DEBOUNCE_DELAY 5 // Define the debounce delay for button presses in milliseconds

PMW3389 sensor(NCS_PIN); // Create an instance of the PMW3389 class with chip select pin 10

struct ButtonState {
  uint8_t pin; // Pin number for the button
  bool lastRead; // Last read state of the button
  bool stableState; // Stable state of the button
  unsigned long lastChangeTime; // Last time the button state changed
};

volatile int8_t scroll = 0; // Variable to hold the position of the rotary encoder

ButtonState buttons[] = {
  {LC_PIN, HIGH, HIGH, 0}, // Initialize the left click button state
  {MC_PIN, HIGH, HIGH, 0},// Initialize the middle click button state
  {RC_PIN, HIGH, HIGH, 0} // Initialize the right click button state
};

void sendMouseMovement(int16_t dx, int16_t dy); // Function prototype for sending mouse movement
void updateButton(ButtonState &button, uint8_t mouseButton); // Function prototype for updating button state
void encoderISR(); // Function prototype for the rotary encoder interrupt service routine

void setup() {
  pinMode(LC_PIN, INPUT_PULLUP); // Set pin 4 as an input with an internal pull-up resistor
  pinMode(RC_PIN, INPUT_PULLUP); // Set pin 9 as an input with an internal pull-up resistor
  pinMode(MC_PIN, INPUT_PULLUP); // Set pin 8 as an input with an internal pull-up resistor
  pinMode(Rot_A_PIN, INPUT_PULLUP); // Set pin 3 as an input with an internal pull-up resistor
  pinMode(Rot_B_PIN, INPUT_PULLUP); // Set pin 7 as an input with an internal pull-up resistor
  Serial.begin(9600); // Initialize serial communication at 9600 baud rate
  if (!sensor.begin()) { // Initialize the PMW3389 sensor and check if it was successful
    while(1); // Stop execution if sensor initialization fails
  }
  Mouse.begin(); // Initialize the Arduino Mouse library
  sensor.setDPI(800); // Set the DPI of the PMW3389 sensor to 800
  attachInterrupt(digitalPinToInterrupt(Rot_A_PIN), encoderISR, CHANGE); // Attach an interrupt to the rotary encoder pin A
}

void loop() {
  PMW3389_Motion motion = sensor.readMotion(); // Read motion data from the PMW3389 sensor
  if (motion.isMotion) { // Check if motion was detected
    sendMouseMovement(motion.dx, motion.dy); // Send mouse movement based on the motion data
  }
  updateButton(buttons[0], MOUSE_LEFT); // Update the state of the left click button
  updateButton(buttons[1], MOUSE_MIDDLE); // Update the state of the middle click button
  updateButton(buttons[2], MOUSE_RIGHT); // Update the state of the right click button
  noInterrupts();
  int8_t scrollAmount = scroll;
  scroll = 0;
  interrupts();
  if (scrollAmount != 0) {
    Mouse.move(0, 0, scrollAmount);
}
}

void sendMouseMovement(int16_t dx, int16_t dy) {
  while (dx != 0 || dy != 0) { // Continue sending mouse movement until both dx and dy are zero
    int8_t moveX = constrain(dx, -127, 127); // Constrain dx to the range of -127 to 127
    int8_t moveY = constrain(dy, -127, 127); // Constrain dy to the range of -127 to 127
    Mouse.move(moveX, moveY); // Move the mouse by the constrained values
    dx -= moveX; // Decrease dx by the amount moved
    dy -= moveY; // Decrease dy by the amount moved
  }
}

void updateButton(ButtonState &button, uint8_t mouseButton) {
  bool currentRead = digitalRead(button.pin); // Read the current state of the button
  if (currentRead != button.lastRead) { // Check if the button state has changed
    button.lastChangeTime = millis(); // Update the last change time to the current time
  }
  if ((millis() - button.lastChangeTime) > DEBOUNCE_DELAY) {
    if (currentRead != button.stableState) { // Check if the stable state has changed
      button.stableState = currentRead; // Update the stable state to the current read
      if (button.stableState == LOW) { 
        Mouse.press(mouseButton); // Call the mouse press function if the button is pressed
      } else {
        Mouse.release(mouseButton); // Call the mouse release function if the button is released
      }
    }
  }
  button.lastRead = currentRead; // Update the last read state to the current read
}

void encoderISR() {
  bool aState = digitalRead(Rot_A_PIN); // Read the state of the rotary encoder pin A
  bool bState = digitalRead(Rot_B_PIN); // Read the state of the rotary encoder pin B
  if (aState != bState) { // Check if the states of the encoder pins are different
    scroll++; // Increment the scroll value if the states are different
  } else {
    scroll--; // Decrement the scroll value if the states are the same
  }
}

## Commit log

2026-07-22 Initial commit: Set up PMW3389 project folder and KiCad files
    [DIY_Mouse.kicad_pcb, DIY_Mouse.kicad_sch]
2026-07-22 Added symbols and footprints for components and created PCB schematic
    [DIY_Mouse.csv, DIY_Mouse.kicad_sch]
2026-07-23 Created PCB design and created GBR and DRL files
    [DIY_Mouse-B_Cu.gbr, DIY_Mouse-B_Mask.gbr, DIY_Mouse-B_Silkscreen.gbr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]
2026-07-23 Changed Pinout for Rotary encoder to hardware interupt pin. Updated README and CHANGELOG files
    [DIY_Mouse-B_Cu.gbr, DIY_Mouse-B_Mask.gbr, DIY_Mouse-B_Silkscreen.gbr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]
2026-08-24 Updated Changelog, credits and readme
    [DIY_Mouse.step]
2026-08-25 PCB v2, Shell 3d model
    [DIY_Mouse.kicad_pcb, DIY_Mouse.step, Mouse Shell bottom.3mf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]
2026-08-26 Completed shell v1
    [Mouse Shell bottom.3mf, Mouse Shell top.3mf, Mouse Shell.3mf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]
2026-08-26 Updated Changelog and scroll knob 3d file
    [Mouse scroll knob.3mf]
2026-08-27 Updated Mouse shell and changelog
    [Mouse Shell bottom.3mf, Mouse Shell knob.3mf, Mouse Shell top.3mf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]
2026-08-27 finished shell v1
    [Mouse Shell bottom.3mf, Mouse Shell knob.3mf, Mouse Shell top.3mf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]
2026-08-27 updated readme and pcb files
2026-08-27 updated readme and pcb
    [DIY_Mouse-B_Cu.gbl, DIY_Mouse-B_Mask.gbs, DIY_Mouse-B_Silkscreen.gbo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]
2026-08-27 Mouse shell v2
    [Mouse Shell bottom.3mf, Mouse Shell knob.3mf, Mouse Shell top.3mf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]
2026-08-27 Mouse shell v2 upgrade
    [Mouse Shell bottom.3mf, Mouse Shell knob.3mf, Mouse Shell top.3mf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]
2026-08-27 edited top shell 3d print files
    [Mouse Shell top.3mf]
2026-08-28 created BOM.md
2026-08-28 Updated BOM.md
2026-08-28 Updated BOM
    [BOM.csv]
2026-08-28 Completed Shell v2, Exported files
    [Mouse Shell bottom.3mf, Mouse Shell knob.3mf, Mouse Shell top.3mf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]
2026-08-28 File Restructure
    [BOM.csv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]
2026-08-28 Updated PCB manufacture files
    [DIY_Mouse.kicad_sch, bom.csv, designators.csv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]
2026-08-28 updated .gitignore
    [bom.csv, designators.csv, positions.csv]
2026-08-28 updated BOM.csv
    [BOM.csv]
2026-08-29 moved pcb files to v2 folder
    [DIY_Mouse.kicad_pcb, DIY_Mouse.kicad_sch, DIY_Mouse.step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]
2026-08-29 Removed incorectly tracked files
    [BOM.csv, DIY_Mouse.kicad_pcb, DIY_Mouse.kicad_sch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]
2026-08-29 adding back files
    [BOM.csv, DIY_Mouse.kicad_pcb, DIY_Mouse.kicad_sch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]
2026-08-29 Updated .gitignore to exclude history folder
    [bom.csv, designators.csv, positions.csv]
2026-08-29 Updated v2 PCB
    [DIY_Mouse.kicad_pcb, DIY_Mouse.kicad_sch]
2026-08-29 Started work on wireless PCB v3
    [Mouse v3.kicad_pcb, Mouse v3.kicad_sch]
2026-08-29 Updated symbol and footprint libraries for v3
2026-08-29 Completed Shell v3
    [Mouse v3.kicad_pcb, Mouse v3.kicad_sch]
2026-08-31 updated shell v2, wider heat insert posts. Updated clicks
    [Mouse Shell bottom.3mf, Mouse Shell top.3mf, Mouse Shell v2.f3z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]
2026-08-31 Changed File Names
    [DIY_Mouse.kicad_pcb, DIY_Mouse.kicad_sch, DIY_Mouse.step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]
2026-08-31 removed accidentally added files
    [BOM.csv, DIY_Mouse.kicad_pcb, DIY_Mouse.kicad_sch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]
2026-08-31 remove addicentally added files
    [BOM.csv, DIY_Mouse.kicad_pcb, DIY_Mouse.kicad_sch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]
2026-09-01 updated PCBs
    [DIY_Mouse.kicad_pcb, Mouse v3.kicad_pcb]
2026-09-02 updated v2 3d printing files
    [Mouse Shell top.3mf, Mouse Shell top.gcode.3mf]
2026-09-02 Updated 3d Printing files for v2
    [Mouse Shell bottom.3mf, Mouse Shell bottom.gcode.3mf, Mouse Shell knob.3mf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]
